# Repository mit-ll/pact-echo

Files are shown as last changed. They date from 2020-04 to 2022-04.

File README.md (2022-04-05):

# PiPACT #

Raspberry Pi based test fixture for development and test of Bluetooth low energy (BLE) contact tracing

### File Layout ###
* pi_pact_backend
    : Backend application built using [Moleculer](https://moleculer.services/)
* pi_pact_frontend
    : Frontend application build using [NextJS](https://nextjs.org/)
* pi_pact_deploy
    : Ansible scripts to install/deploy application
* isolated_tests
    : Set of standalone scripts to validate/test software library support for specific features

---
## Disclaimer

DISTRIBUTION STATEMENT A. Approved for public release: distribution unlimited.

© 2020 MASSACHUSETTS INSTITUTE OF TECHNOLOGY

    Subject to FAR 52.227-11 – Patent Rights – Ownership by the Contractor (May 2014)
    SPDX-License-Identifier: MIT

This material is based upon work supported by the United States Air Force under Air Force Contract No. FA8721-05-C-0002 and/or FA8702-15-D-0001. Any opinions, findings, conclusions or recommendations expressed in this material are those of the author(s) and do not necessarily reflect the views of the Name of United States Air Force.

The software/firmware is provided to you on an As-Is basis

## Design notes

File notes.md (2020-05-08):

# Links and Libraries
## Node Libraries
* [node-blecon](https://github.com/sandeepmistry/node-bleacon)
    * Note: It's unclear what this add over noble and bleno
    * Issue: [Cannot find module 'bluetooth-hci-socket'](https://github.com/noble/bleno/issues/440) - Downgrade Node
* Noble
    * Issue: [Doesn't compile on RPi 3B+](https://github.com/noble/node-bluetooth-hci-socket/issues/107)
        * `npm install bluetooth-hci-socket@npm:@abandonware/bluetooth-hci-socket`
## Node
* [How to Updgrade or Downgrade Nodejs Using npm](https://www.surrealcms.com/blog/how-to-upgrade-or-downgrade-nodejs-using-npm.html)
## System Prerequisits
* `sudo apt-get install bluetooth bluez libbluetooth-dev libudev-dev`

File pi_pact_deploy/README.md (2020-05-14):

# pipact-deploy
Automated deployment for PiPACT project. 

## Hardware Support
* Raspberry Pi 3
* Raspberry Pi 3B+

## Manual Steps
1. Write [Raspian Buster Lite](https://www.raspberrypi.org/downloads/raspbian/) imaged to SD card
1. Boot Pi and connect to internet via Wi-Fi or Ethernet
1. Enable ssh
    1. `$ sudo raspi-config`
    1. Select **5 - Interfacing Options**
    1. Select **P2 - SSH**
    1. Select **Yes**
    1. Select **Finish**
1. Set timezone using raspi-config
    1. `$ sudo raspi-config`
    1. Select **4 - Localisation Options**
    1. Select **I2 - Change Timezone**
    1. Select appropriate timezone
    1. Select **Finish**
1. Install ansible and git
    : `$ sudo apt install -y ansible git`
1. Clone web project
    1. Anticipate this can go away once we real github/npm
1. `$ cd pipact/deploy`
1. `$ ansible-galaxy install -r requirements.yml`
1. `$ ansible-playbook pipact.yml`

## Notes and References
* [Running Your Node.js App with Systemd - Part 1](https://nodesource.com/blog/running-your-node-js-app-with-systemd-part-1/)
* During development it was useful to set 2 environment varibles:
    * `$ export ANSIBLE_CACHE_PLUGIN=jsonfile`
    * `$ export ANSIBLE_CACHE_PLUGIN_CONNECTION=/home/pi/cache.json`
* [How To Install and Configure NATS on Ubuntu 16.04](https://www.digitalocean.com/community/tutorials/how-to-install-and-configure-nats-on-ubuntu-16-04)

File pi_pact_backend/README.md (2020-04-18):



# pi_pact_web
This is a [Moleculer](https://moleculer.services/)-based microservices project. Generated with the [Moleculer CLI](https://moleculer.services/docs/0.14/moleculer-cli.html).

## Usage
Start the project with `npm run dev` command. 
After starting, open the http://localhost:3000/ URL in your browser. 
On the welcome page you can test the generated services via API Gateway and check the nodes & services.

In the terminal, try the following commands:
- `nodes` - List all connected nodes.
- `actions` - List all registered service actions.
- `call greeter.hello` - Call the `greeter.hello` action.
- `call greeter.welcome --name John` - Call the `greeter.welcome` action with the `name` parameter.

## Services
- **api**: API Gateway services
- **greeter**: Sample service with `hello` and `welcome` actions.

## Useful links

* Moleculer website: https://moleculer.services/
* Moleculer Documentation: https://moleculer.services/docs/0.14/

## NPM scripts

- `npm run dev`: Start development mode (load all services locally with hot-reload & REPL)
- `npm run start`: Start production mode (set `SERVICES` env variable to load certain services)
- `npm run cli`: Start a CLI and connect to production. Don't forget to set production namespace with `--ns` argument in script
- `npm run lint`: Run ESLint
- `npm run ci`: Run continuous test mode with watching
- `npm test`: Run tests & generate coverage report

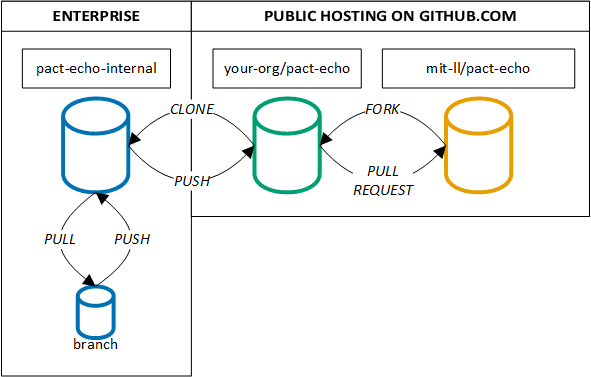
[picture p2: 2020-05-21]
images/workflow.png

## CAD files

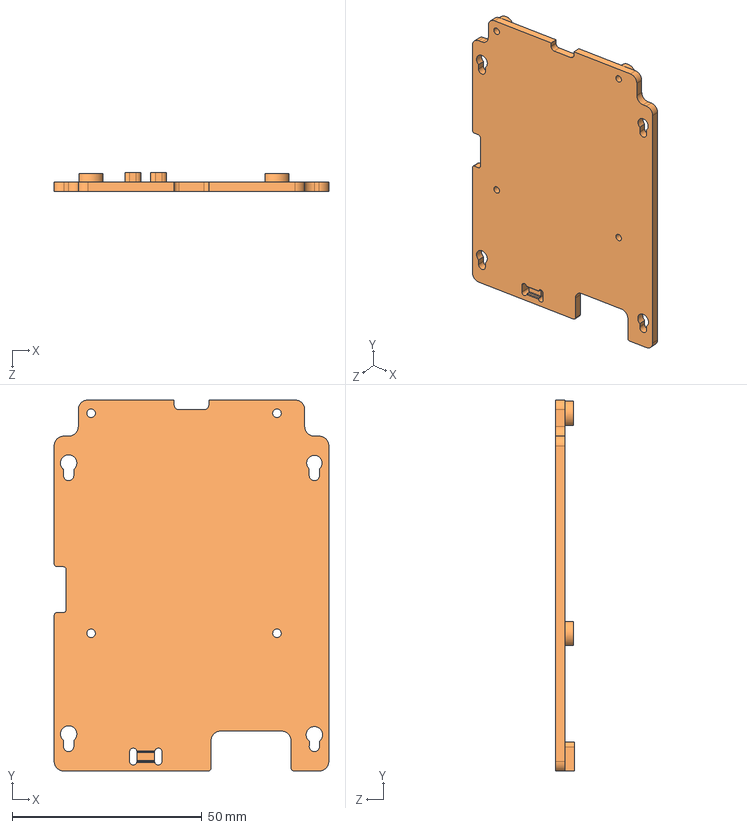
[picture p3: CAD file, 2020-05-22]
hardware/enclosure/Pi base.STEP
72.4 x 97.8 x 5.08 mm

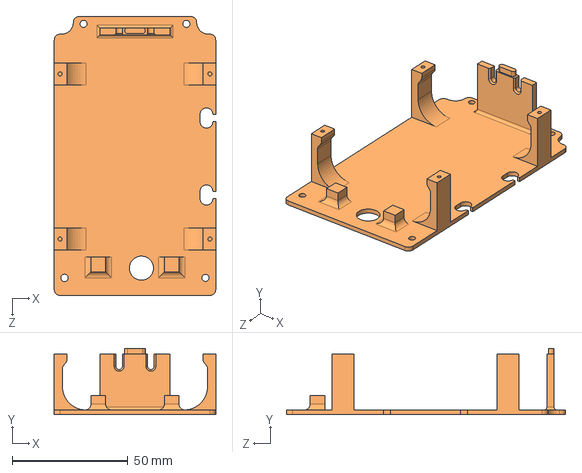
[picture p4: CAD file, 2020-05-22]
hardware/enclosure/Battery Base - Induction Charge.STEP
69.8 x 28.7 x 120.6 mm

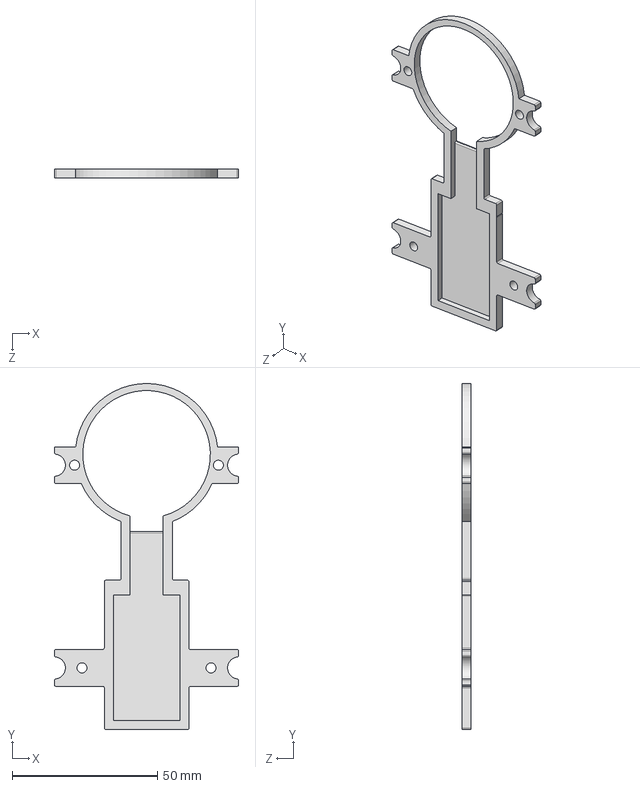
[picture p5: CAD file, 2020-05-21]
hardware/enclosure/Charge RX.STEP
63.5 x 119.2 x 3.18 mm

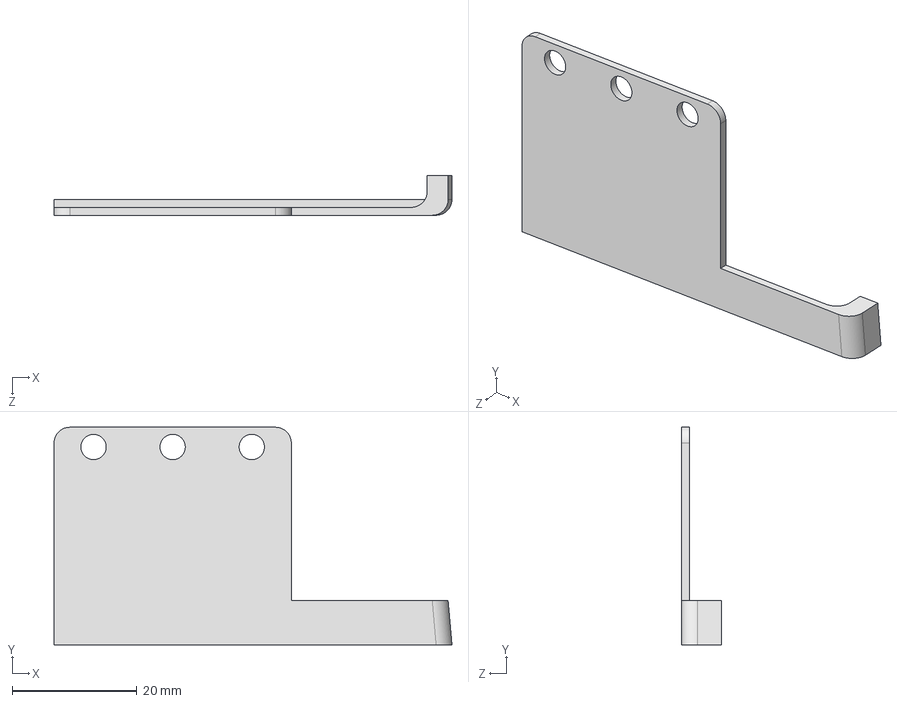
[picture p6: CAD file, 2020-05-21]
hardware/enclosure/LED template.STEP
63.9 x 34.9 x 6.35 mm

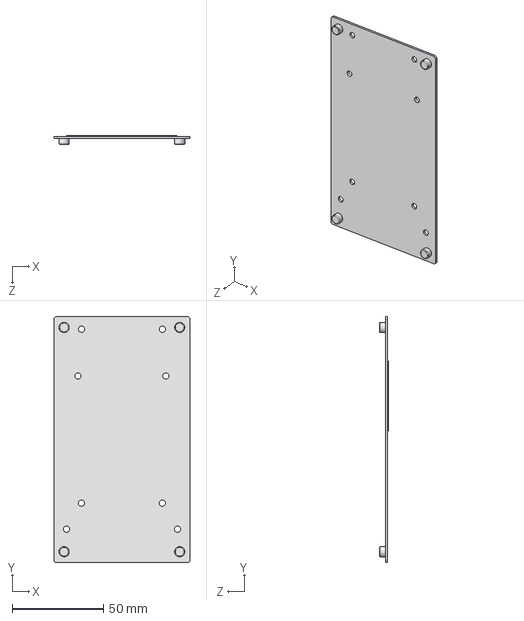
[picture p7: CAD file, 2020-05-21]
hardware/enclosure/Hole template.STEP
74.7 x 135.1 x 4.95 mm

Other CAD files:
hardware/enclosure/Battery Base - Induction Charge.STL
hardware/enclosure/Charge RX.STL
hardware/enclosure/Hole template.STL
hardware/enclosure/LED template.STL
hardware/enclosure/Pi base.STL

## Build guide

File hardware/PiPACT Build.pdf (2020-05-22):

PiPACT System Build

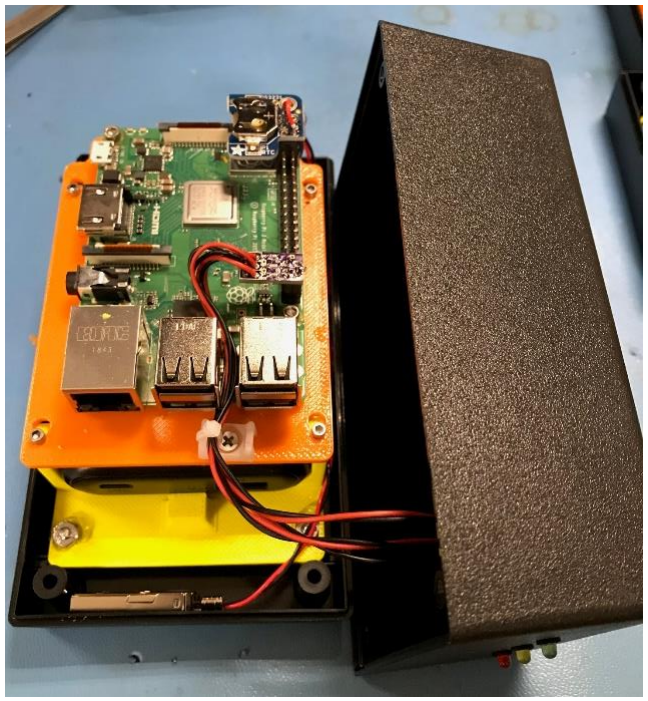
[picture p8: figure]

Table of Contents:
Cable assembly
Enclosure modification
Assembly
Build of materials

### Cable Assembly

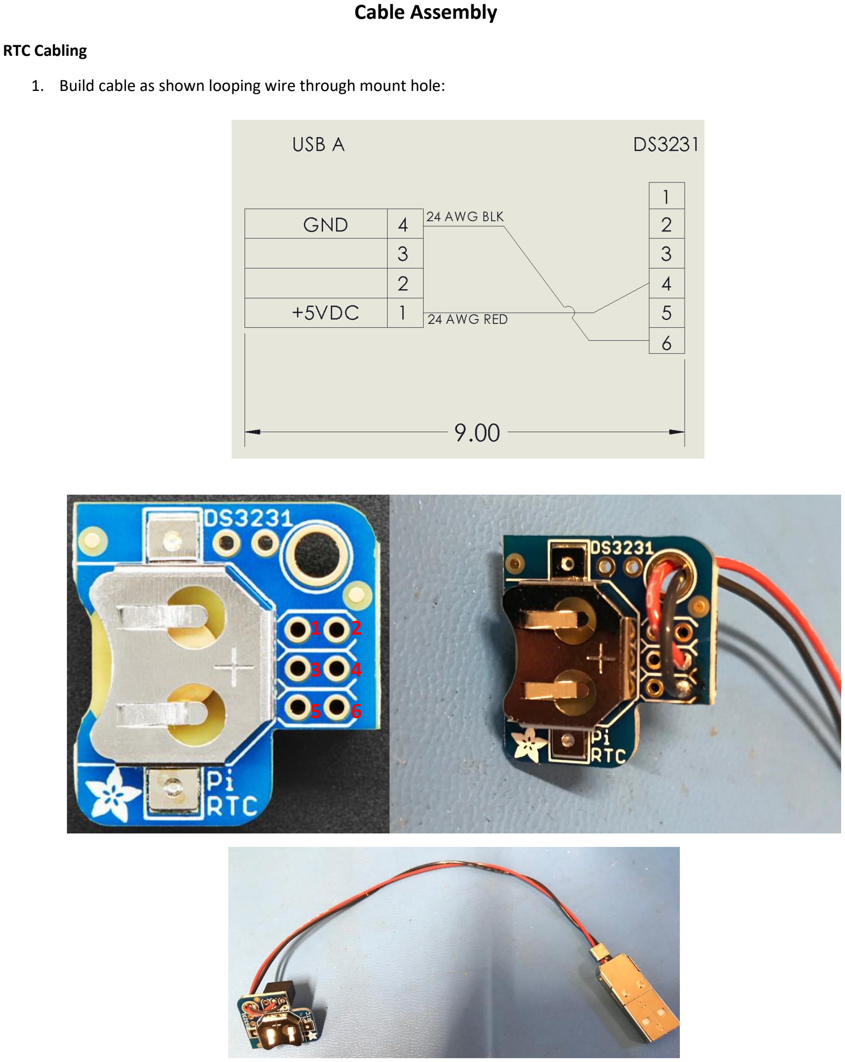
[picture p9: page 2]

RTC Cabling

1. Build cable as shown looping wire through mount hole:

1 2

3 4

5 6

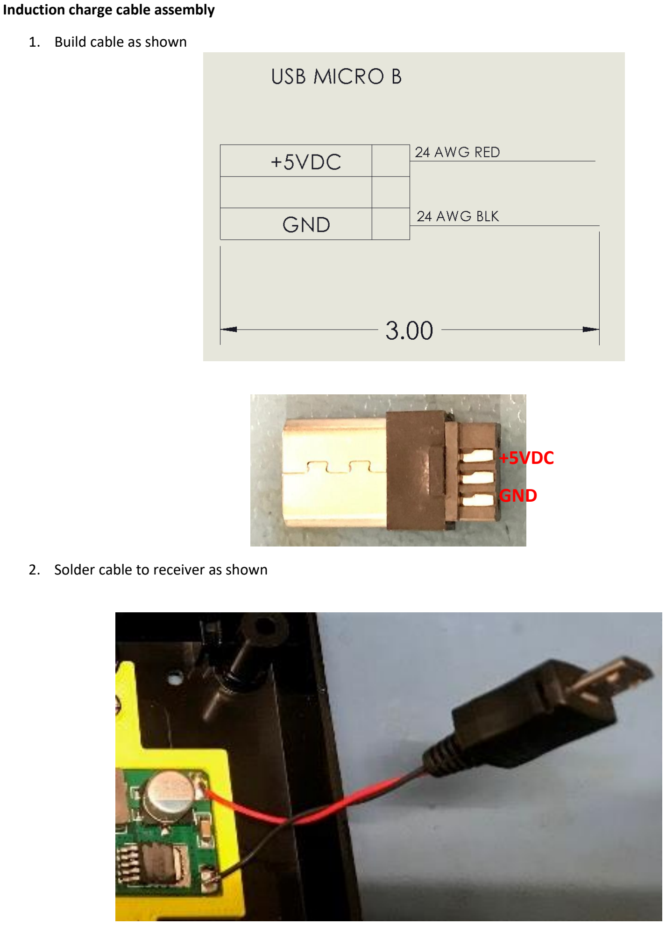
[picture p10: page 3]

Induction charge cable assembly

1. Build cable as shown
2. Solder cable to receiver as shown

### +5VDC

### GND

### Enclosure Modification

Top lid assembly

1. Use template to drill three .16” holes

Bottom Lid

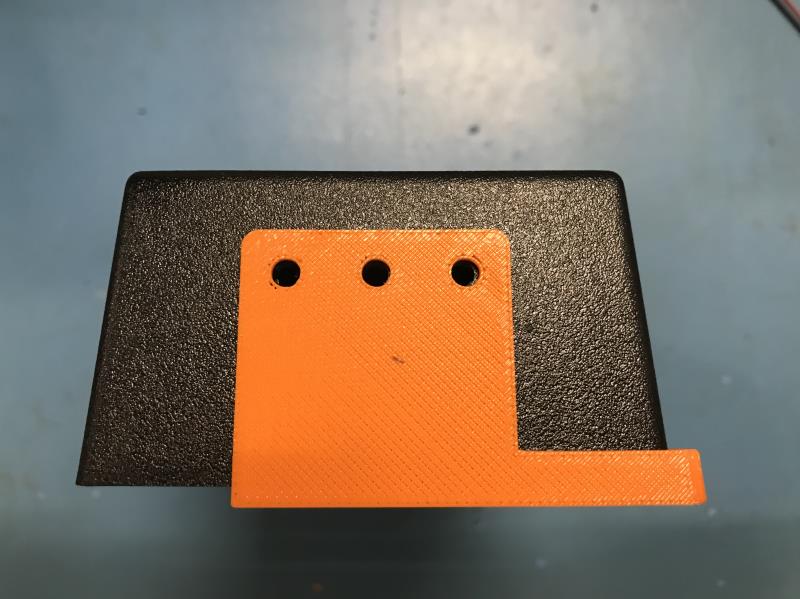
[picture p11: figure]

1. Use template to drill eight .112” holes

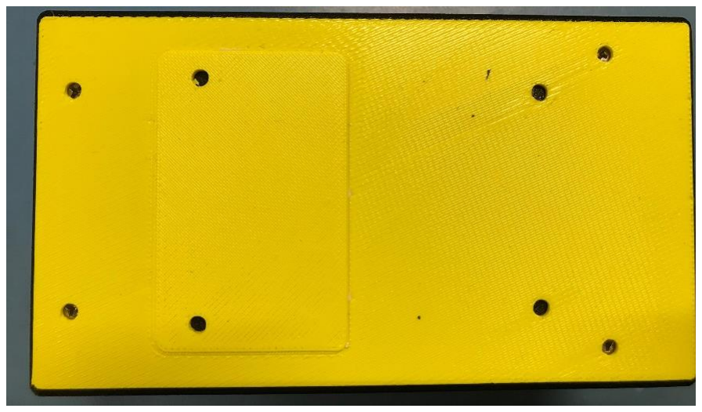
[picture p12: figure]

2. Use 82° counter sink bit on all 8 holes

### Assembly

Top Lid

1. Insert LEDS in order
2. Solder LED’s to PCB hat:

Green – 21
Yellow – 20
Red – 26

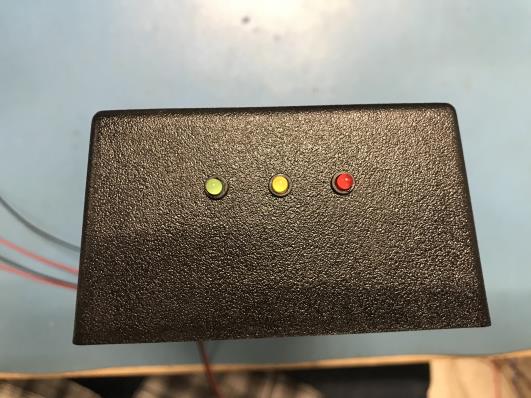
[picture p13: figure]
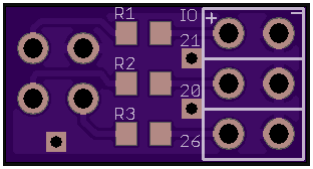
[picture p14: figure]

Battery Frame

1. Tap four 2-56 holes

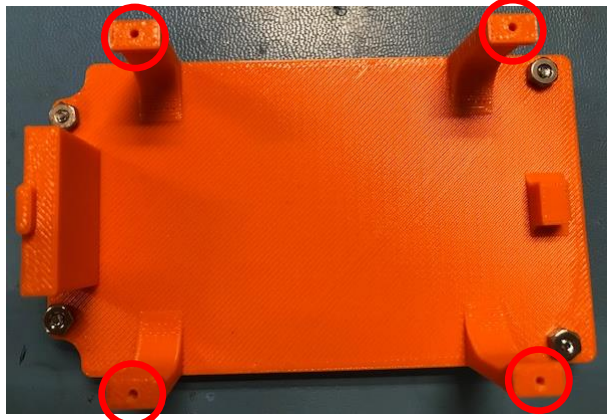
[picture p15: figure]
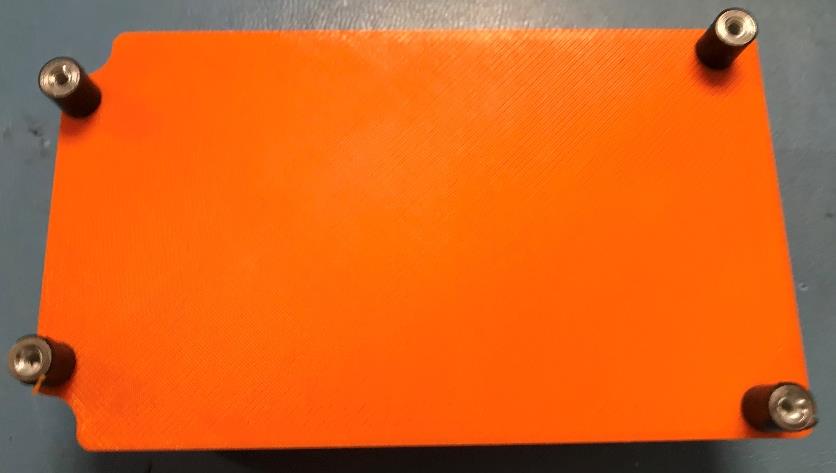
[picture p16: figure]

2. Install vibration dampers (96905k35) with #4 nuts (90480A005)
3. Add RTV to all nuts

Raspberry Pi Frame

1. Tap four 4-40 holes

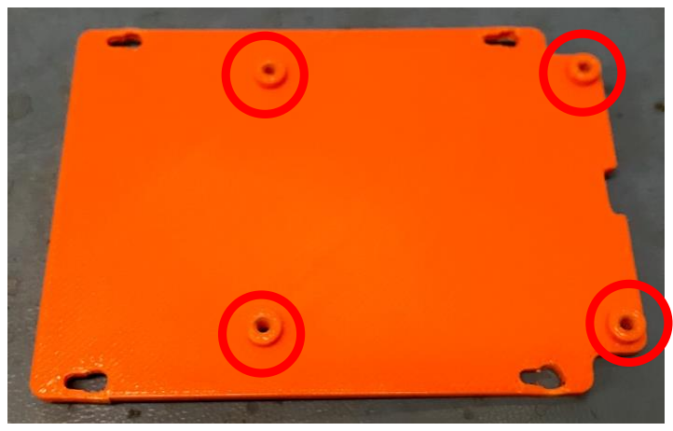
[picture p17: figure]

2. Install Raspberry Pi with four #4 screws (92196a106)
3. Add RTV to all screws

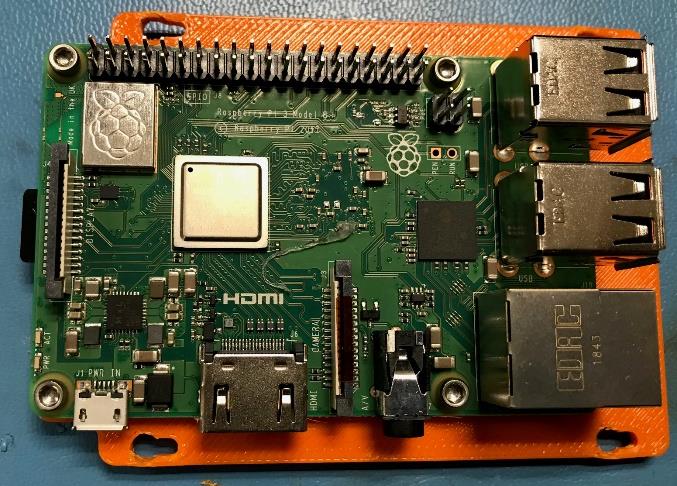
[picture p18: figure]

4. Add 2” foam (93275K113) to bottom of frame

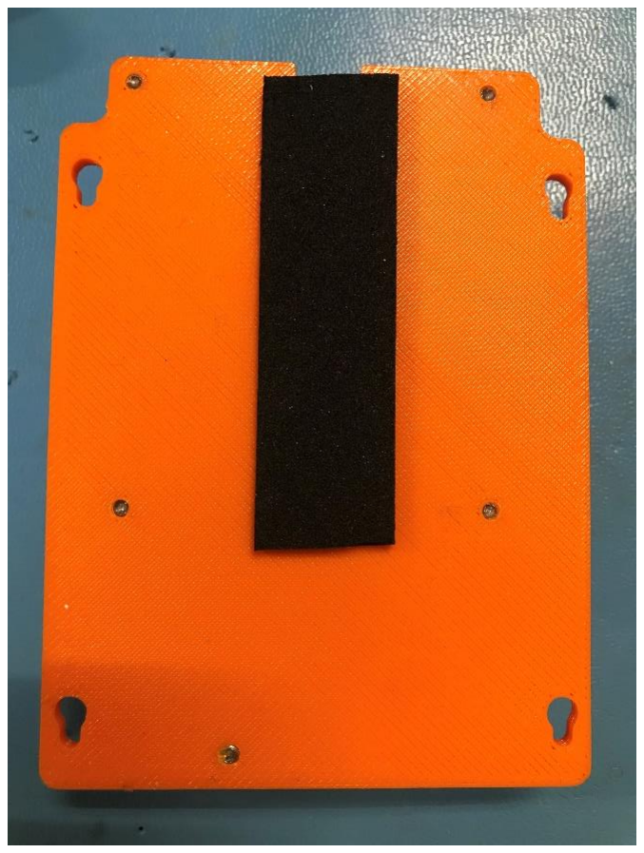
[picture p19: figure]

Induction charge assembly

1. Place induction charge receiver frame into bottom lid using four 4-40 flathead screws (91771A108) and locknuts (90633a005). Place RTV in frame.

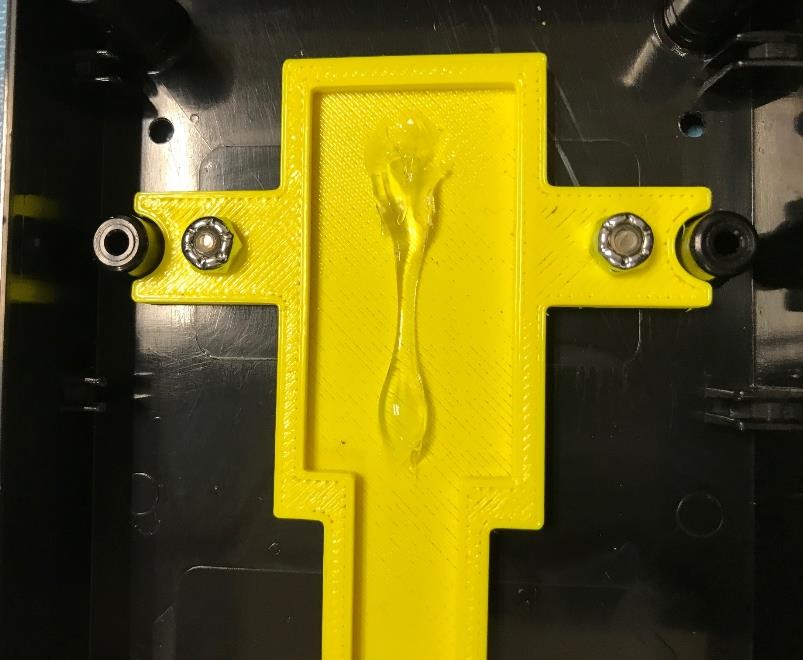
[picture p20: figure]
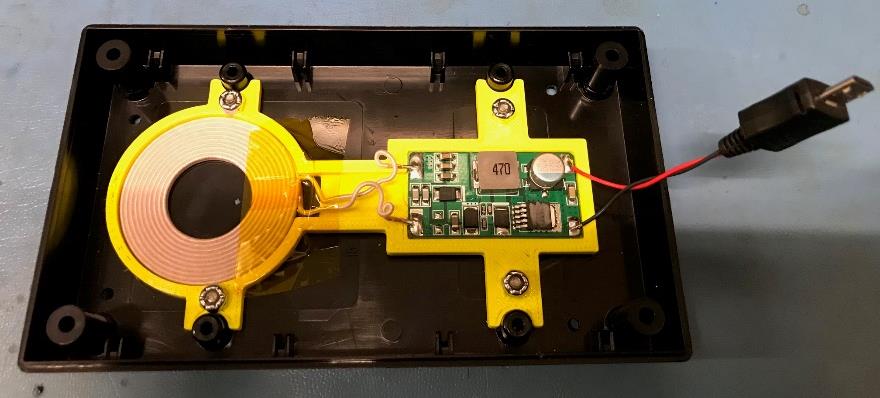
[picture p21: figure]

2. Add induction charge receiver assembly to frame adding kapton tape over coil

Frame assembly

1. Add battery frame assembly to bottom lid using four 4-40 screws (91771a106) with 242 Loctite.

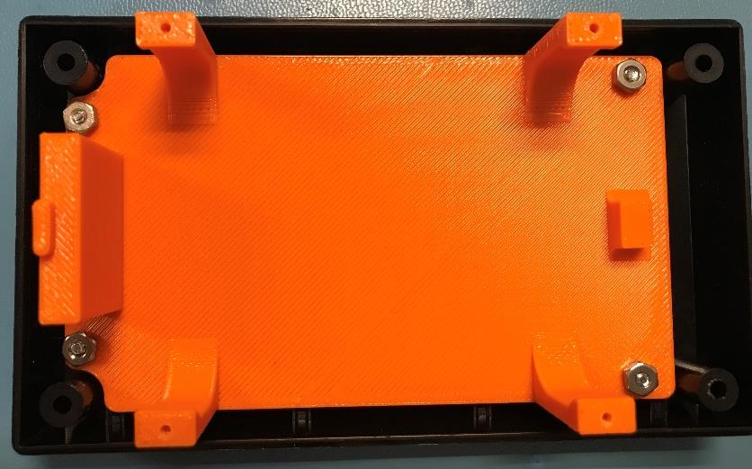
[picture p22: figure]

2. Add battery and Raspberry Pi frame assembly. Hand tight the screws to securing both frames.
3. Connect RTC cable assembly to pins 1-6 on the Raspberry Pi. Add RTV.

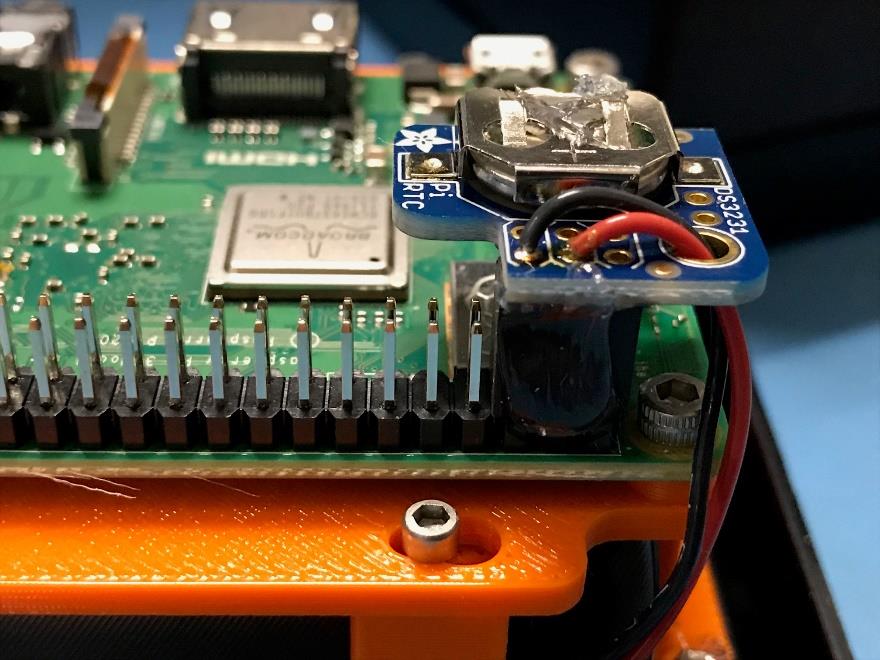
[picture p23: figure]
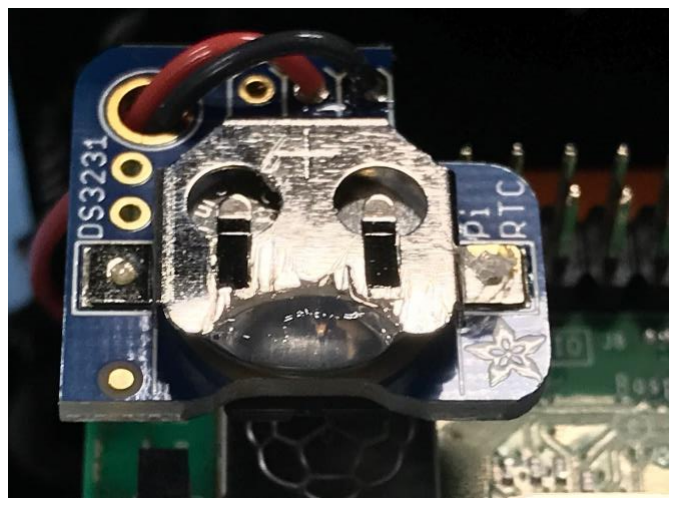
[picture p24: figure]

4. Insert CR1220 battery to RTC. Add RTV.

LED Hat assembly

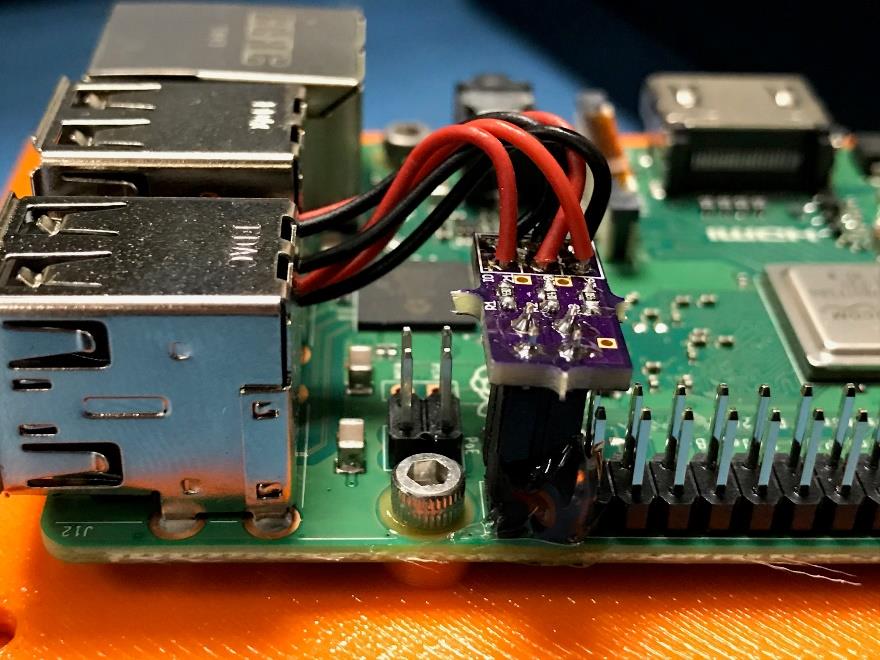
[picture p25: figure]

1. Connect GPIO hat to pins 37-40 on Raspberry Pi. Add RTV.

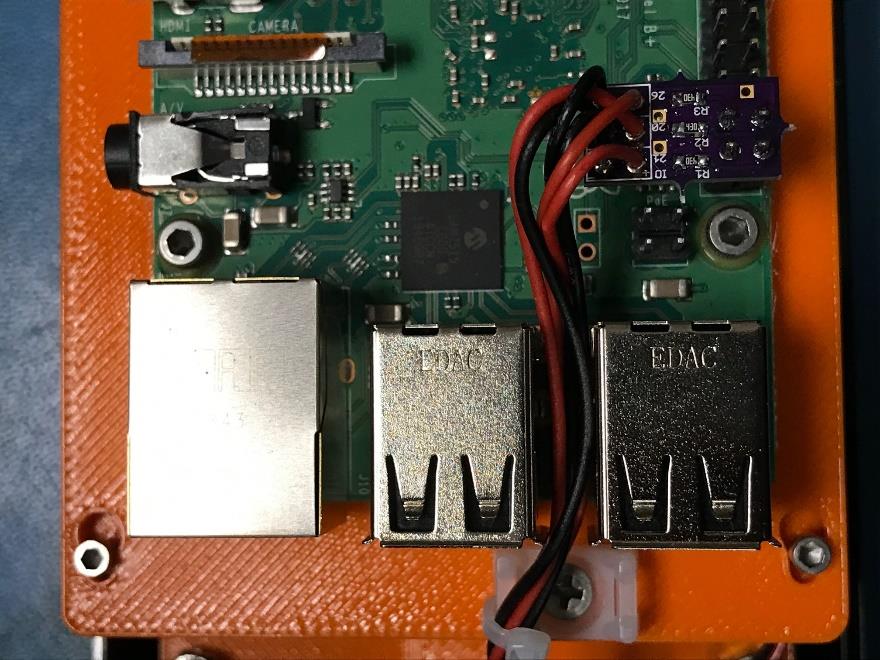
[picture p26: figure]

2. Zip tie cables to mount

Build of Materials

Electronics | Quantity
Raspberry Pi 3 B+ | 1 | https://www.digikey.com/product-detail/en/raspberry-pi/RASPBERRY-PI-3-MODEL-B/1690-1025-ND/8571724
Battery | 1 | https://www.amazon.com/dp/B072MH1434/ref=emc_b_5_t
RTC | 1 | https://www.digikey.com/product-detail/en/adafruit-industries-llc/4282/1528-4282-ND/10287040
USB A | 1 | https://www.digikey.com/product-detail/en/adafruit-industries-llc/1827/1528-1396-ND/5629444
USB Micro B | 1 | https://www.digikey.com/product-detail/en/adafruit-industries-llc/1390/1528-1182-ND/5353642
LED (Green) | 1 | https://www.digikey.com/product-detail/en/bivar-inc/PM3GDW12-0/492-1612-ND/3488910
LED (Red) | 1 | https://www.digikey.com/product-detail/en/bivar-inc/PM3RDW12-0/492-1616-ND/3488901
LED (Yellow) | 1 | https://www.digikey.com/product-detail/en/bivar-inc/PM3YDW12-0/492-1617-ND/3488906
MicroSD 32Gb | 1 | https://www.govconnection.com/product/sandisk-32gb-microsdhc-flash-memory-card-class-4/sdsdq-032g-a46/15912248
Induction charging | 1 | https://www.digikey.com/product-detail/en/adafruit-industries-llc/4430/1528-4430-ND/11569133

Hardware
Nuts | 4 | https://www.mcmaster.com/90480A005-90480A005
Locknuts | 4 | https://www.mcmaster.com/90633a005
4-40 Screws (Socket) | 4 | https://www.mcmaster.com/92196a106
4-40 Screws (FH, 3/16) | 4 | https://www.mcmaster.com/91771a106
4-40 Screws (FH, 3/8) | 4 | https://www.mcmaster.com/91771A108-91771A108
2-56 screws | 4 | https://www.mcmaster.com/92196a077
Foam | 1 | https://www.mcmaster.com/93275K113
Loctite | 1 | https://www.mcmaster.com/91458A112
Enclosure | 1 | https://www.mcmaster.com/7593k29
Damper | 4 | https://www.mcmaster.com/96905k35

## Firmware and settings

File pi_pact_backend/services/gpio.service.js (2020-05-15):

/* 
 *  DISTRIBUTION STATEMENT A. Approved for public release. Distribution is unlimited.
 *  
 *  This material is based upon work supported by the United States Air Force under
 *   Air Force Contract No. FA8702-15-D-0001. Any opinions, findings, conclusions 
 *   or recommendations expressed in this material are those of the author(s) and 
 *   do not necessarily reflect the views of the United States Air Force.
 *  
 *  (c) 2020 Massachusetts Institute of Technology.
 *  
 *  The software/firmware is provided to you on an As-Is basis
 *  
 *  Delivered to the U.S. Government with Unlimited Rights, as defined in 
 *  DFARS Part 252.227-7013 or 7014 (Feb 2014). Notwithstanding any copyright
 *  notice, U.S. Government rights in this work are defined by DFARS 252.227-7013 
 *  or DFARS 252.227-7014 as detailed above. Use of this work other than as 
 *  specifically authorized by the U.S. Government may violate any copyrights 
 *  that exist in this work.
 */

"use strict";

const rpio = require('rpio');
const util = require('util');
const exec = util.promisify(require('child_process').exec);

module.exports = {
    name: "gpio",

    settings: {
        red_pin: 26,
        yellow_pin: 20,
        green_pin: 21,
        wifi_pin: 16,
        period_timer: null
    },

    async started() {
        rpio.init({ mapping: 'gpio' });
        rpio.open(this.settings.wifi_pin, rpio.INPUT, rpio.PULL_UP);
        rpio.poll(this.settings.wifi_pin, this.toggle_wifi);
        rpio.open(this.settings.yellow_pin, rpio.OUTPUT, rpio.LOW);
        rpio.open(this.settings.red_pin, rpio.OUTPUT, rpio.LOW);
        rpio.open(this.settings.green_pin, rpio.OUTPUT, rpio.LOW);
        this.settings.period_timer = setInterval(this.pollServices, 10000); //10 second interval
    },

    async stopped() {
        clearInterval(this.settings.period_timer);
        rpio.open(this.settings.yellow_pin, rpio.OUTPUT, rpio.LOW);
        rpio.open(this.settings.red_pin, rpio.OUTPUT, rpio.LOW);
        rpio.open(this.settings.green_pin, rpio.OUTPUT, rpio.LOW);

    },

    dependencies: [
        "system-state",
        "recorder",
        "scanner",
        "beacon"
    ],


    events: {
        "advertisment.received"(ctx) {

        }
    },

    actions: {

    },

    methods: {
        async pollServices() {
            const scanner = await this.broker.call('scanner.status');
            const recorder = await this.broker.call('recorder.status');
            const beacon = await this.broker.call('beacon.status');
            const system_state = await this.broker.call('system-state.state');

            // console.log("Scanner %s\tRecorder %s\tBeacon %s", scanner.running, recorder.running, beacon.running)
            // console.log("Bluetooth: %s", system_state.rf.bluetooth);
            // console.log("WLAN: %s", system_state.rf.wlan);

            if (scanner.running) {
                this.blink_once(this.settings.red_pin, 1000);
            }

            if (recorder.running) {
                this.blink_once(this.settings.yellow_pin, 1000);
            }

            if (beacon.running) {
                this.blink_once(this.settings.green_pin, 1000);
            }

            if (system_state.rf.wlan.soft == 'unblocked' &&
                system_state.rf.wlan.hard == 'unblocked') {
                // console.log("Wi-Fi on");
                setTimeout(this.wifi_on, 1250);
            }
        },

        async blink_once(pin, mTime) {
            this.pin_on(pin);
            setTimeout(this.pin_off, mTime, pin);
        },

        async blink_twice(pin) {
            this.pin_on(pin);
            setTimeout(this.pin_off, 250, pin)
            setTimeout(this.pin_on, 500, pin);
            setTimeout(this.pin_off, 750, pin);
        },

        async pin_on(pin) {
            rpio.write(pin, rpio.HIGH);
        },

        async pin_off(pin) {
            rpio.write(pin, rpio.LOW);
        },

        async wifi_on() {
            this.pin_on(this.settings.green_pin);
            setTimeout(this.pin_on, 500, this.settings.yellow_pin);
            setTimeout(this.pin_on, 1000, this.settings.red_pin);
            setTimeout(this.pin_off, 1500, this.settings.green_pin);
            setTimeout(this.pin_off, 1500, this.settings.yellow_pin);
            setTimeout(this.pin_off, 1500, this.settings.red_pin);
        },

        async toggle_wifi(cbpin) {
            if (rpio.read(cbpin)) {
                console.log("Button released");
                //Get current state
                const system_state = await this.broker.call('system-state.state');
                console.log('Toggle State: %s', system_state);
                if (system_state.rf.wlan.soft == 'unblocked') {
                    //Disable WLAN
                    await exec("rfkill block wlan");
                } else {
                    //Enable WLAN
                    await exec("rfkill unblock wlan");
                }
            }
        }
    }


}

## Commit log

2020-04-23 Pretty print byte values
2020-05-13 Read button press to toggle wifi
2020-05-13 added analysis routines and hardware files; inserted copyright headers
    [Battery Base - Induction Charge.STEP, Battery Base - Induction Charge.STL, Charge RX.STEP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]
2020-05-22 updated mechanical build documents
    [Battery Base - Induction Charge.STEP, Battery Base - Induction Charge.STL, Pi base.STEP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]
